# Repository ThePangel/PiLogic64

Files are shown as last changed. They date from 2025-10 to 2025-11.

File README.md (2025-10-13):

# PiLogic64 🎮✨

> An open-source logic puzzle console 
## What is this?

**PiLogic64** is a handheld logic puzzle gaming console powered by a Raspberry Pi Pico. This project brings interactive logic puzzles and games to makers everywhere—at a fraction of the cost and with infinite customizability.

### Features 🚀

- **8x8 NeoPixel Matrix Display** - Bright, colorful LED matrix for puzzle visualization
- **OLED Screen** - Navigate menus and game selection with ease
- **Dual Rotary Encoders** - Intuitive controller input for puzzle solving
- **Audio Output** - Up to dual speakers for satisfying sound effects and feedback
- **SD Card Support** - Easily add new puzzles and games by dropping files on an SD card
- **Rechargeable Power** - 2 18650 Li-ion battery with TP4056 charging circuit and MT3608 buck converter for stable 5V power
- **100% Open Source** - PCB designs, schematics, and code available for the community

### Tech Specs 🔧

- **Microcontroller**: Raspberry Pi Pico (or Pico 2)
- **Display**: 8x8 NeoPixel Matrix + OLED
- **Power**: 2 18650 cells (3.7V) → TP4056 charger → MT3608 boost to 5V
- **Audio**: PAM8403 amplifier
- **Input**: 2x Rotary Encoders
- **Storage**: SD Card slot

## Game Examples 🎯

Here are some games I have thought for the PiLogic64!
(Some I will code myself, but feel free to make any of these!)

### Logic Puzzles
- **Mastermind** - Crack the color code using logic and deduction
- **Color Sudoku** - 8x8 Sudoku with colored LEDs instead of numbers
- **Lights Out** - Toggle lights to turn them all off in a cascading puzzle
- **Pattern Memory** - Simon-style memory game with increasing sequences
- **Minesweeper** - Classic logic game adapted for the LED matrix

### Action Games
- **Snake** - Classic snake game with colorful trails
- **Tetris Mini** - Block-stacking puzzle on a compact grid

### Creative Puzzles

- **Color Match** - Pattern matching and replication challenges
- **Logic Gates** - Educational puzzles teaching boolean logic

*...and infinitely more! Just code and drop new game files on the SD card.*

## Development Journey 📔

This project is being documented on [Hack Club Blueprint](https://blueprint.hackclub.com/projects/380). Check it out for detailed build logs, photos, and the full story!

## Credit
-   Footprints
    - [MT3608](https://github.com/kubabuda/misc_footprints/)
    -   [TP4056](https://github.com/ccadic/TP4056-18650) (I did modify this one)
    -   [PAM8403](https://github.com/johnnycubides/pam8403-module-kicad-lib/tree/main) (I did modify this one)
    -   [BK-18650-PC4](https://www.snapeda.com/parts/BK-18650-PC4/Memory%20Protection%20Devices/view-part/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)

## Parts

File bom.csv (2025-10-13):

Id | Designator | Footprint | Quantity | Designation | Supplier and ref | Unit Price (€) | Total Price (€)
1 | LED1 | WS2812_8x8_Matrix | 1 | WS2812 LED 5050 8X8 LED MATRIX | AliExpress | 2.25 | 2.25
2 | SP1,SP2 | Speaker_2809 | 2 | 2809 SPEAKER | AliExpress | 2.27 | 5.35
3 | D1 | D_DO-41_SOD81_P10.16mm_Horizontal | 1 | 1N5817 DIODE | AliExpress | 0.2 | 1.36
4 | BT1 | 18650_Dual_Holder | 1 | 18650 DUAL BATTERY HOLDER | AliExpress | 1.71 | 1.71
5 | U3 | PAM8403_Module | 1 | PAM8403 MODULE | AliExpress | 0.46 | 1.38
6 | SW1,SW2 | RotaryEncoder_Alps_EC11E-Switch_Vertical_H20mm | 2 | EC11 ENCODER | AliExpress | 1.21 | 2.43
7 | OLED1 | OLED_0.96_I2C | 1 | 0.96 INCH OLED I2C | AliExpress | 1.99 | 1.99
8 | U4 | MT3608_Module | 1 | MT3608 MODULE | AliExpress | 0.74 | 1.48
9 | SD1 | MicroSD_Reader | 1 | MICRO SD CARD READER | AliExpress | 0.80 | 0.80
10 | U5 | TP4056_Module | 1 | TP4056 MODULE | AliExpress | 0.34 | 1.71
11 | U1 | RPi_Pico2_SMD_TH | 1 | RASPBERRY PI PICO 2 | AliExpress | 5.69 | 5.69
12 | BAT | 18650 | 2 | 18650 | AliExpress | 3.18 | 6.26
13 | PCB1 | Custom_PCB | 1 | CUSTOM PCB (shipping included) | JLCPCB | 30.10 | 30.10

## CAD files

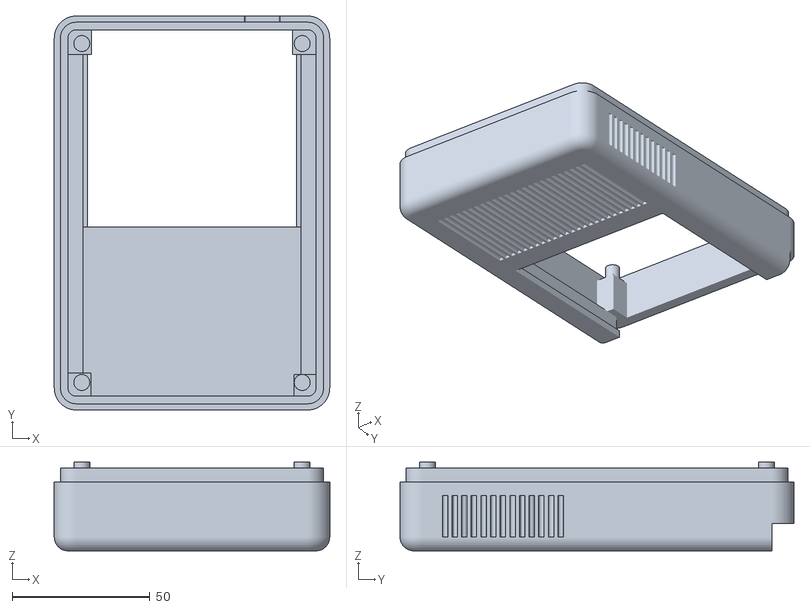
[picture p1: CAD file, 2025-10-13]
3DModels/Main_Body.stl
100.0 x 143.0 x 32.2

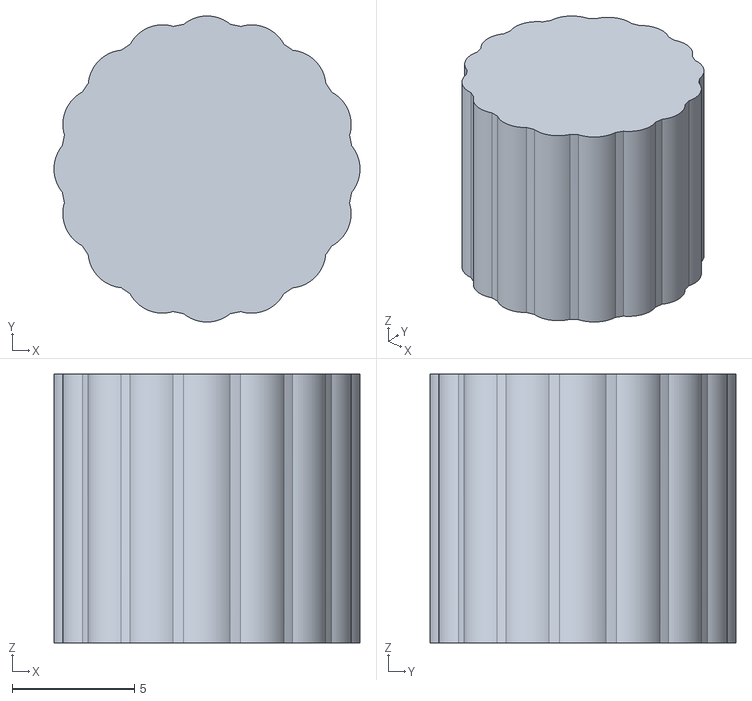
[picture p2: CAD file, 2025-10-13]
3DModels/Knob.stl
12.5 x 12.5 x 11.0

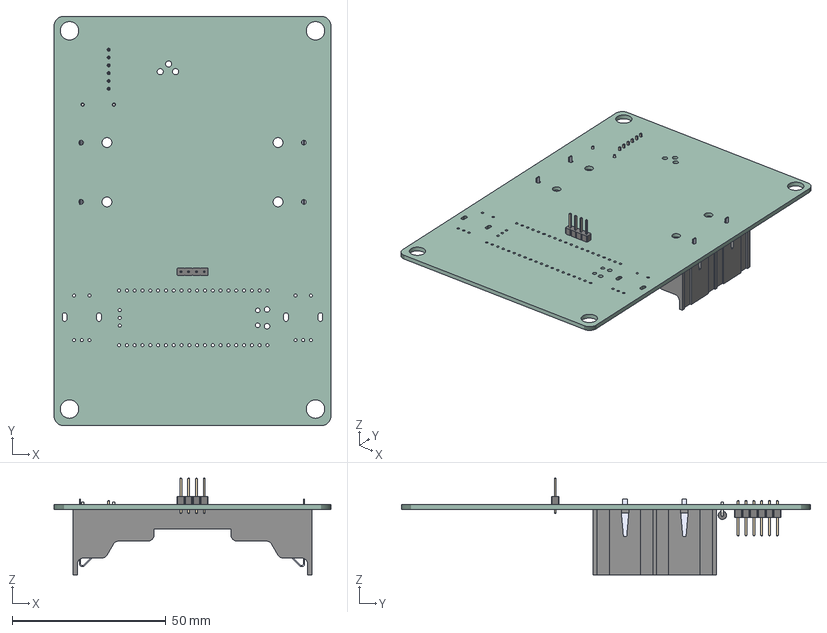
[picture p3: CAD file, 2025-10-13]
pcb/pilogic64.step
90.0 x 133.0 x 31.5 mm
PinHeader_1x04_P254mm_Vertical
D_DO-41_SOD81_P10.16mm_Horizontal
BK-18650-PC4
PinHeader_1x06_P254mm_Vertical
pilogic64 PCB

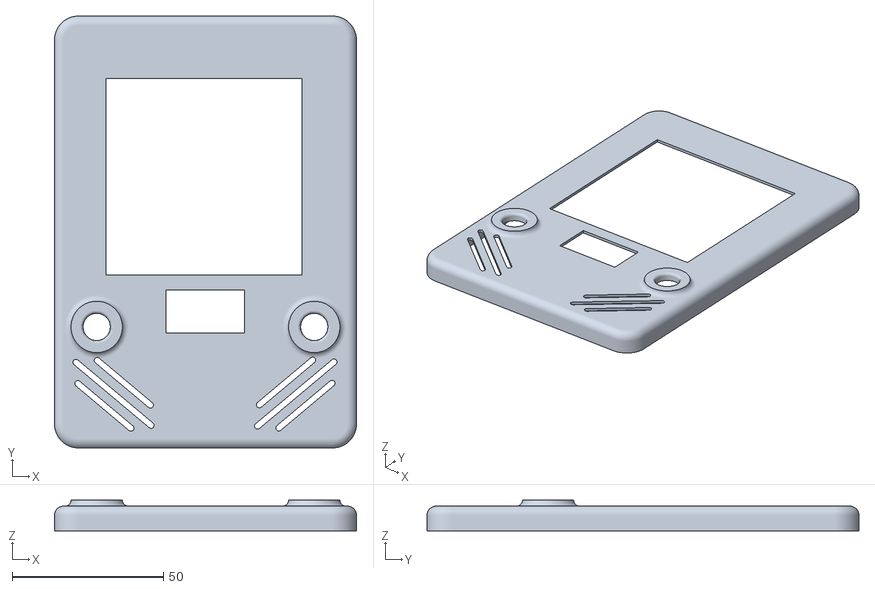
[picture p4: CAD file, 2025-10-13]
3DModels/Front.stl
100.0 x 143.0 x 10.2

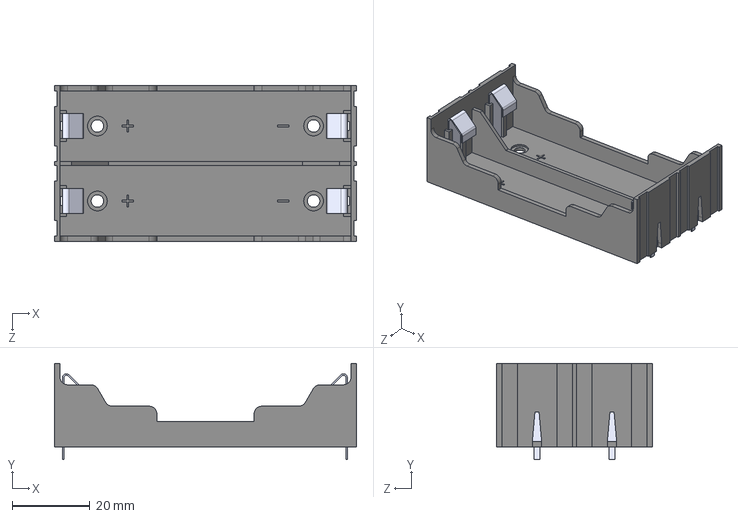
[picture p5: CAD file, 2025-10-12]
pcb/3dmodels/BK-18650-PC4.step
77.7 x 24.7 x 40.2 mm

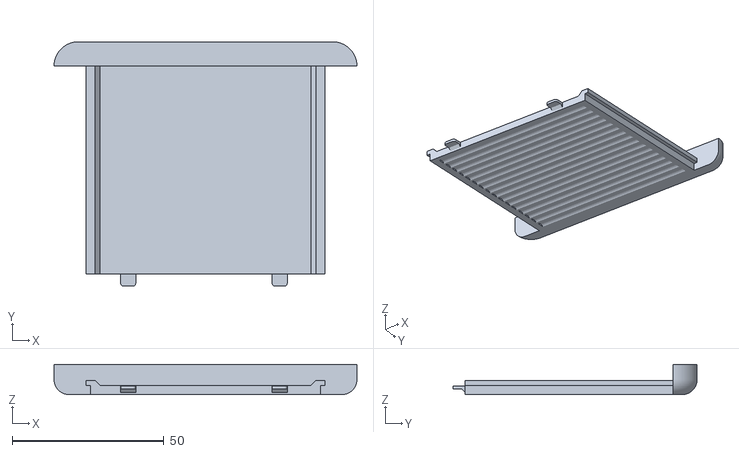
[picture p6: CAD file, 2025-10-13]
3DModels/Battery_door.stl
100.0 x 80.7 x 10.0

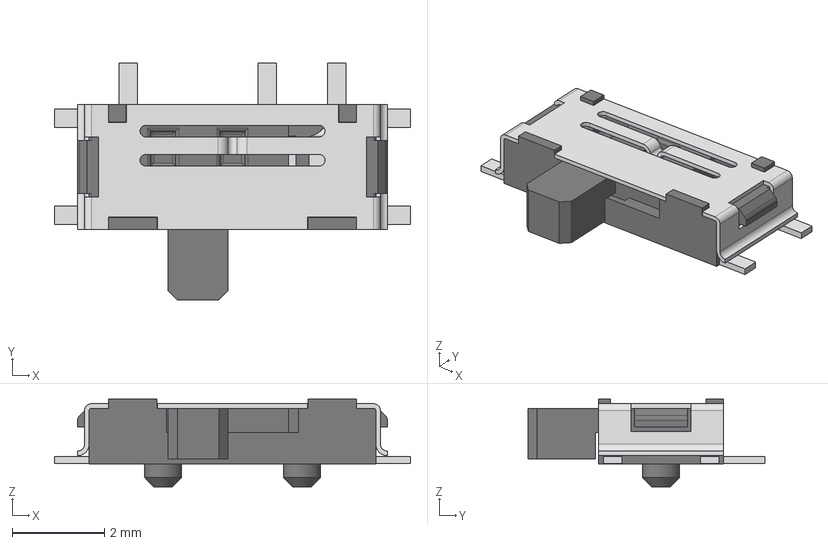
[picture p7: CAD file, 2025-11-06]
pcb/3dmodels/450404015514.step
7.70 x 5.13 x 1.90 mm
Frame
Pin 4
Frame 1
Pin 1
Pin 2
Pin 3
Slider 1
Slider
Cover

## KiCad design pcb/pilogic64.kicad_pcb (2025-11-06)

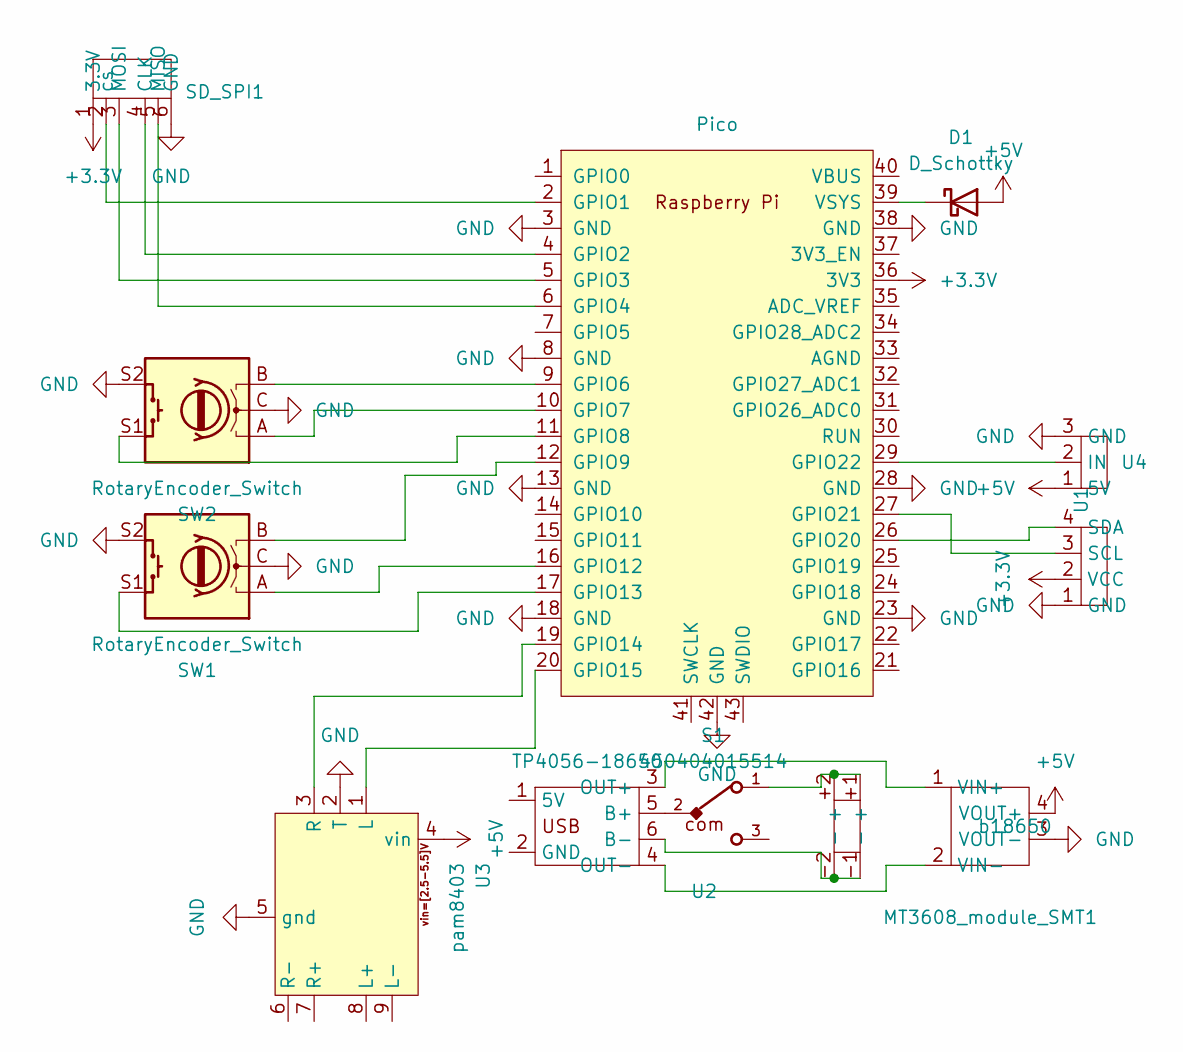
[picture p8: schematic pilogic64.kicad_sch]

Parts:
D1: D_Schottky; D_DO-41_SOD81_P10.16mm_Horizontal
MT3608_module_SMT1: MT3608_module_SMT
S1: 450404015514
SD_SPI1: PinHeader_1x06_P2.54mm_Vertical
SW1, SW2: RotaryEncoder_Switch; RotaryEncoder_Alps_EC11E-Switch_Vertical_H20mm
TP4056-18650: TP4056-18650
U1: PinHeader_1x04_P2.54mm_Vertical
U2: Pico; RPi_Pico_SMD_TH
U3: pam8403
U4: 8x8 MAtrix
b18650: 18650-PC4

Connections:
+3.3V: SD_SPI1.1 (3.3V), U1.2 (VCC), U2.36 (3V3)
+5V: D1.2 (A), MT3608_module_SMT1.4 (VOUT+), U3.4 (vin), U4.1 (5V)
GND: MT3608_module_SMT1.3 (VOUT-), S1.Z1, S1.Z2, S1.Z3, S1.Z4, SD_SPI1.6 (GND), SW1.C, SW1.MP, SW1.S2, SW2.C, SW2.MP, SW2.S2, U1.1 (GND), U2.3 (GND), U2.8 (GND), U2.13 (GND), U2.18 (GND), U2.23 (GND), U2.28 (GND), U2.38 (GND), U2.42 (GND), U3.2 (T), U3.5 (gnd), U4.3 (GND)
unnamed: D1.1 (K), U2.39 (VSYS)
unnamed: MT3608_module_SMT1.1 (VIN+), TP4056-18650.3 (OUT+)
unnamed: MT3608_module_SMT1.2 (VIN-), TP4056-18650.4 (OUT-)
unnamed: S1.1, b18650.+1 (+), b18650.+2 (+)
unnamed: SD_SPI1.4 (CLK), U2.4 (GPIO2)
unnamed: SD_SPI1.5 (MISO), U2.6 (GPIO4)
unnamed: SD_SPI1.3 (MOSI), U2.5 (GPIO3)
unnamed: SD_SPI1.2 (cs), U2.2 (GPIO1)
unnamed: S1.2, TP4056-18650.5 (B+)
unnamed: TP4056-18650.6 (B-), b18650.-1 (-), b18650.-2 (-)
unnamed: U1.3 (SCL), U2.27 (GPIO21)
unnamed: U1.4 (SDA), U2.26 (GPIO20)
unnamed: SW2.B, U2.9 (GPIO6)
unnamed: SW2.A, U2.10 (GPIO7)
unnamed: SW2.S1, U2.11 (GPIO8)
unnamed: SW1.B, U2.12 (GPIO9)
unnamed: SW1.A, U2.16 (GPIO12)
unnamed: SW1.S1, U2.17 (GPIO13)
unnamed: U2.19 (GPIO14), U3.3 (R)
unnamed: U2.20 (GPIO15), U3.1 (L)
unnamed: U2.29 (GPIO22), U4.2 (IN)

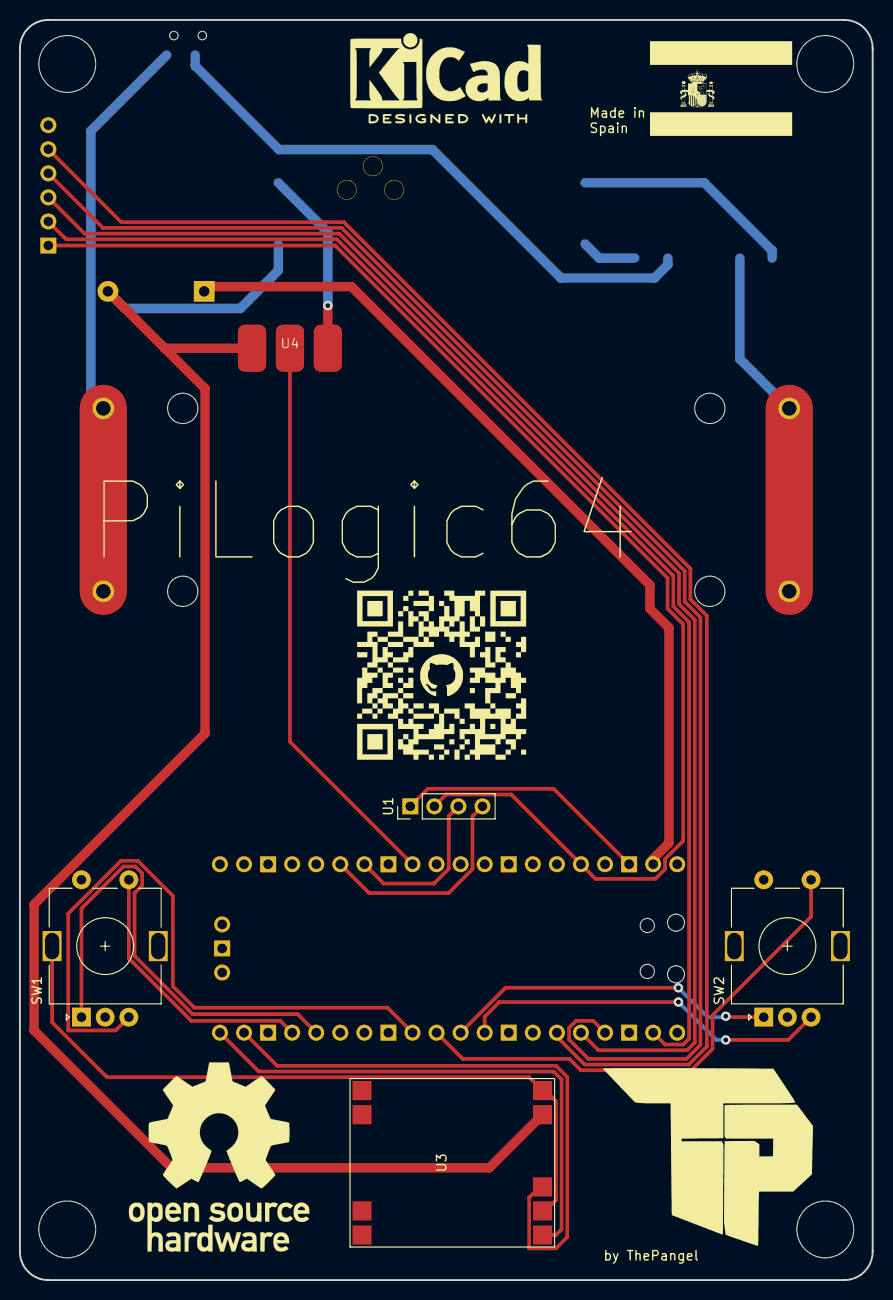
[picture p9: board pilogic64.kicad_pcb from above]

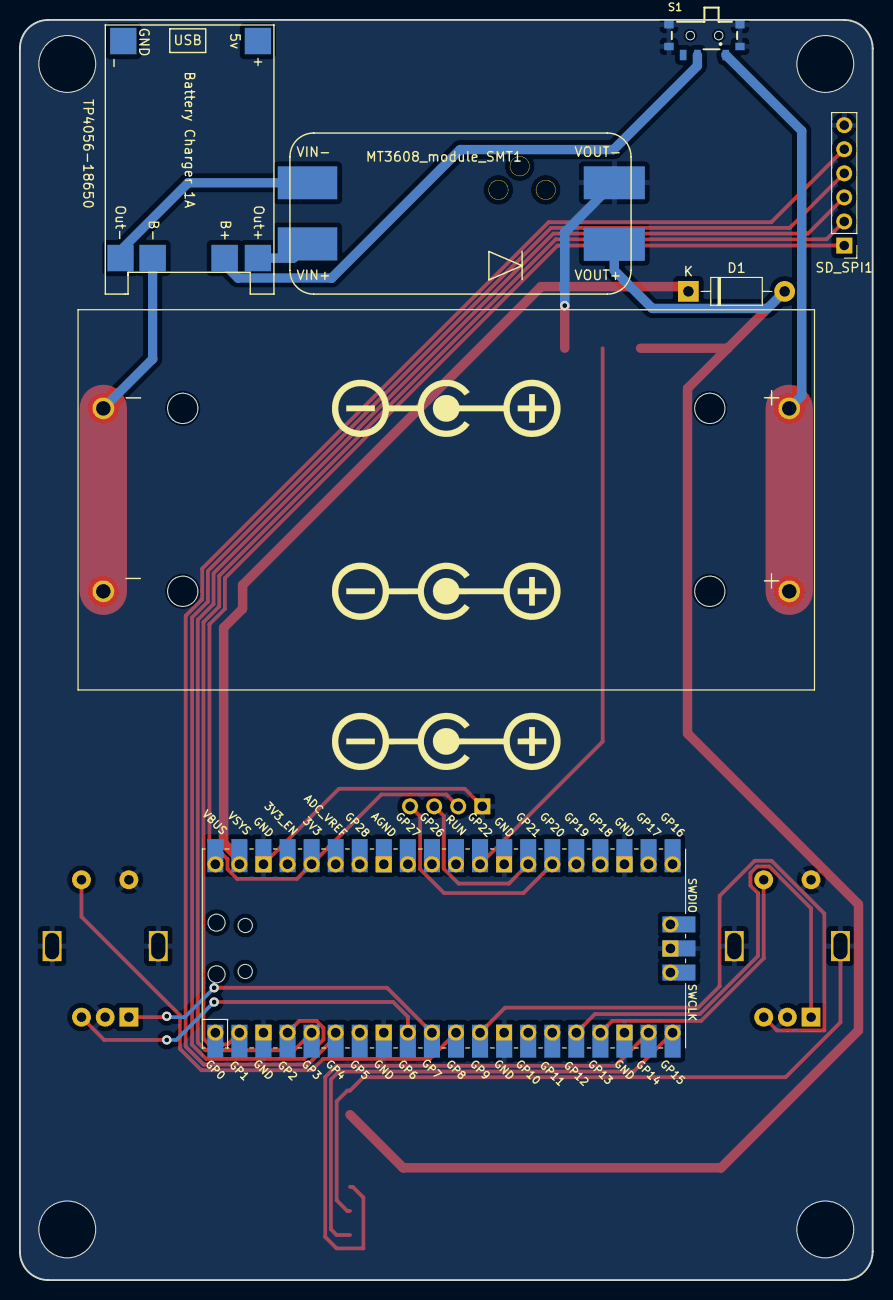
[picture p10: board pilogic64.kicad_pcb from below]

Board: 2 copper layers, 90.0 x 133.0 mm, 12 parts (7 on the bottom side), 24 nets.

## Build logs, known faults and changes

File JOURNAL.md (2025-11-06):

<!--
  ===================    !!READ THIS NOTICE!!   ====================
  DO NOT edit this file manually. Your changes WILL BE OVERWRITTEN!
  This journal is auto generated and updated by Hack Club Blueprint.
  To edit this file, please edit your journal entries on Blueprint.
  ==================================================================
-->

## 10/10/2025 4:20 PM - Research and organization  

Imma get started with explaining what I'm doing.

The other day I was watching reels and saw this


But then I saw the price, 50€, a hell nah twin.

So I decided I'm gonna make a open source logic puzzle console with a bunch of puzzles and games you can easily program and add to an SD card, using an 8x8 neopixel matrix as the display, one OLED as a screen to navigate menus, two rotary encoders as controller input 

I did a bunch of research and designed some stuff in my mind and winded up with that, I also will be using a 2.7V battery and a battery charger + buck converter to power the thing.

I spent like, 2 hours, probably more testing circuits with components I have lying around the house, so I have a material list ready, I need to tests the components and design the pcb.  

## 10/10/2025 4:54 PM - Quick correction   

I meant 3.7V, not 2.7)
V, a 18650 cell to be exact, with the TC4056 as a charging circuit and a buck converter to go up to 5V and power the pico + matrix.

This should power everything and with the Pico's efficiency the main power drawer is the matrix, but brightness will be adjustable, I also forgot to mention I plan to add a buzzer/speaker for little sounds and such


## 10/11/2025 - PCB and curcuit  

I started working on making the PCB, made a bunch of symbols and most of the circuit
Screenshot 2025-10-11 194230.png

I still have the amp, speakers and oled to go but It's mostly done.
As for the PCB I have an initial wip layout done Screenshot 2025-10-11 194056.png
Screenshot 2025-10-11 194021.png

And a better and more complete shopping cart!


Going quick cause this project is mostly software sooo
Seya!

## 10/12/2025 - Finishing of circuit, PCB layout + research  

I added the speaker amp into the circuit, and made the PCB layout more efficient, it can now fit two cells for extra battery! plus some other icons, and made research on how the amp works + other stuff 

Now I'm onto the 3D modeling for the case and LED diffusion.


Screenshot 2025-10-12 204116.png

## 10/13/2025 12 AM - Made a 3D model  

I made a 3d case, it has a door for hot swapping batteries, made on F360 for 3D printing, I will be printing and testing fits tonight, I tried to keep it as thin as possible but 3D printing has its limitations, and I lack some measurements for some components, but all will be fixed with time!
pilogic64 v1.png
pilogic64 v1 3.png
pilogic64 v1 2.png

## 10/13/2025 4 PM - Final 3D model and PCB  

I have made some big changes too the 3D model, I saw some issues after printing it myself, some dimension issues that came from the pcb holes, which I have fixed, also usb didn't fit so my bad, fixed that aswell, so last thing I need is a BOM will I will make soon!

  pilogic64 v4.png
pilogic64 v4 2.png

## 10/13/2025 6 PM - BOM, routing  

Finished routing the PCB, changed SD card orientation cause it ain't fitting any other way.
Screenshot 2025-10-13 172104.png
I have a BOM ready and setup, I use a pico 2 (1 should work) for the brains, a OLED display for menu navigation, an 8x8 matrix as the game screen, two rotary encoder as input, and a audio amp and two speakers for sound. Powering that are two 18650 cells charged by a TP4056 and boosted to 5V, with an SD card to easily and dynamically import games.
 Screenshot 2025-10-13 172042.png

## 10/21/2025 - Parts arrived! Testing!  

So the parts (But the batteries) got here today! I have been all evening testing each component individually and they all work great' now that I can take the final measurements for everything i will soon finish the PCB + 3D case and then can get to coding everything together!! looking promising!
(please ignore my mess of a desk)
 



## 10/25/2025 - Final PCB + Final 3D model and more!  

I finally finished and ordered the PCB, biggest change is the power switch (totally forgot abt it), I took one from a cheap gift console and used that so I don't need to buy anything, Also finished the case, now the pcb needs to arrive and be assembles and then time to code


DSCF0628


## 11/5/2025 - Got the PCB, time to solder  

So here is the thing, I SUCK at soldering so this took too much tie cause a bunch of mishaps, but I got it assembled!! I'm waiting for the 3d printed case to print and start coding!! 
(Sorry for the shit ahh images my phone camera is cracked)


## 11/6/2025 - Some code & misshaps  

Today I started to code, but because an oversight I broke the pico by stressing the USB port, but fear not, I will desolder it, put some female header conectors and plug a PicoH in there, so its an upgrade since we can now hot swap picos!


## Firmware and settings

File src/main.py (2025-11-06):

from machine import Pin, SPI
from machine import I2C
from ssd1306 import SSD1306_I2C
import neopixel
import time
import os, sdcard

REC1_A = 12
REC1_B = 12
REC1_SW = 13

REC2_A = 7
REC2_B = 6
REC2_SW = 8

AUD_R = 14
AUD_L = 15

MATX = 22

DSP_SDA = 20
DSP_SCL = 21

SD_CS = 1
SD_MOSI = 3
SD_CLK = 2
SD_MISO = 4

clk1 = Pin(REC1_A, Pin.IN, Pin.PULL_UP)
dt1 = Pin(REC1_B, Pin.IN, Pin.PULL_UP)
sw1 = Pin(REC1_SW, Pin.IN, Pin.PULL_UP)

clk2 = Pin(REC2_A, Pin.IN, Pin.PULL_UP)
dt2 = Pin(REC2_B, Pin.IN, Pin.PULL_UP)
sw2 = Pin(REC2_SW, Pin.IN, Pin.PULL_UP)

built_games = ["Mastermind", "Snake", "Sudoku"]
game_idx = 0

matrix = neopixel.NeoPixel(Pin(MATX), 64)
matrix.write()

dsp = I2C(0, scl=Pin(DSP_SCL), sda=Pin(DSP_SDA))
oled = SSD1306_I2C(128, 64, dsp)

card = spi = SPI(0,
          baudrate=1_000_000,  
          polarity=0,
          phase=0,
          bits=8,
          firstbit=SPI.MSB,
          sck=Pin(SD_CLK),
          mosi=Pin(SD_MOSI),
          miso=Pin(SD_MISO))

sd = sdcard.SDCard(card, Pin(SD_CS))

os.mount(sd, "/")

oled.fill(0)

oled.text("Initializing...",4 , 32)
                   
oled.show()

time.sleep(0.5)

last_step1 = clk1.value()
last_step2 = clk2.value()
print(len(built_games) - 1)
while True:
    clk_now = clk1.value()
    dt_now = dt1.value()

    if clk_now == 1 and last_step1 == 0:  
        if dt_now != clk_now:
            game_idx = (game_idx + 1) % len(built_games)
        else:
            game_idx = (game_idx - 1) % len(built_games)
    last_step1 = clk_now


    clk2_now = clk2.value()
    dt2_now = dt2.value()

    if clk2_now == 1 and last_step2 == 0:  
        if dt2_now != clk2_now:
            game_idx = (game_idx + 1) % len(built_games)
        else:
            game_idx = (game_idx - 1) % len(built_games)
    last_step2 = clk2_now
    
    oled.fill(0)
    prev_idx = (game_idx - 1) % len(built_games)
    next_idx = (game_idx + 1) % len(built_games)

    oled.text(built_games[prev_idx], (128 - len(built_games[prev_idx]) * 8) // 2, 8)
    oled.text(built_games[game_idx], (128 - len(built_games[game_idx]) * 8) // 2, 32)
    oled.text(built_games[next_idx], (128 - len(built_games[next_idx]) * 8) // 2, 56)
    oled.show()
    
    last_step1 = current_step1
    last_step2 = current_step2

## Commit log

2025-10-11 Initial structure plus some pcb stuff
    [pilogic64.kicad_pcb, pilogic64.kicad_sch]
2025-10-11 Fixed symbols plus other changes
    [pilogic64.kicad_sch]
2025-10-11 More pcb!
    [pilogic64.kicad_pcb, pilogic64.kicad_sch]
2025-10-12 Finished cicuit, and I think also finished pcb
    [BK-18650-PC4.step, pilogic64.kicad_pcb, pilogic64.kicad_sch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]
2025-10-12 Add credits
    [pilogic64.step]
2025-10-13 added 3d models and some pcb tweaks
    [Battery_door.stl, Front.stl, Knob.stl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]
2025-10-13 Finished PCB, added BOM
    [BOOM.csv, pilogic64.kicad_pcb, pilogic64.step]
2025-10-13 Add BOM file for components used in the project
    [bom.csv]
2025-10-13 Update BOM file with supplier and pricing information
    [bom.csv]
2025-10-13 Edit BOM file
    [BOOM.csv, bom.csv]
2025-11-06 Add new symbols for components and remove lock files; implement main functionality for game selection on microcontroller
    [450404015514.step, pilogic64.kicad_pcb, pilogic64.kicad_sch]
